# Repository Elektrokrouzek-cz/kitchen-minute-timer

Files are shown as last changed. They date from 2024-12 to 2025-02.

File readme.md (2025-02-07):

# Kitchen minute timer
This is the construction of simple kitchen minute timer based on logical 
circuits (4060, 4040, 4081 and 2x 4017). It was designed for beginners to 
train SMD components soldering (all passive components have 1206 packages).

PCB is 4-layer and was designed using KiCad 8. Fabrication output for JLCPCB is in gerber folder.

Happy soldering!

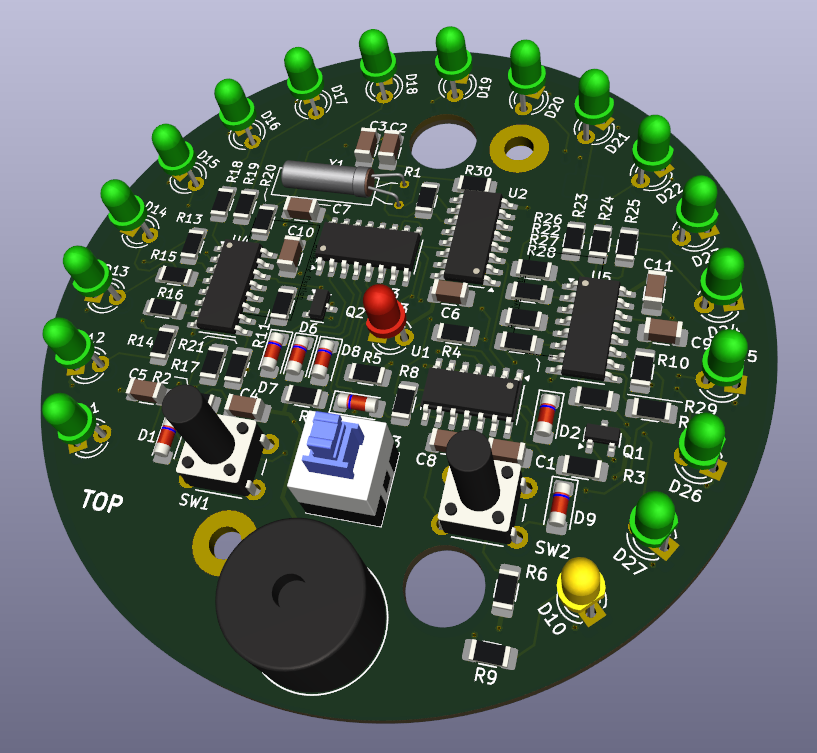
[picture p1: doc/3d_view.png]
3D view

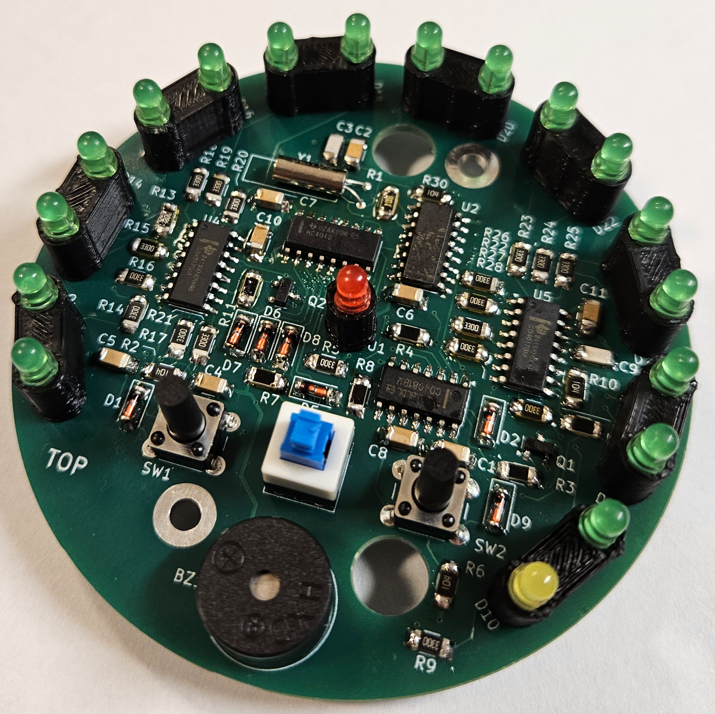
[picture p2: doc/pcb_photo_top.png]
PCB Top

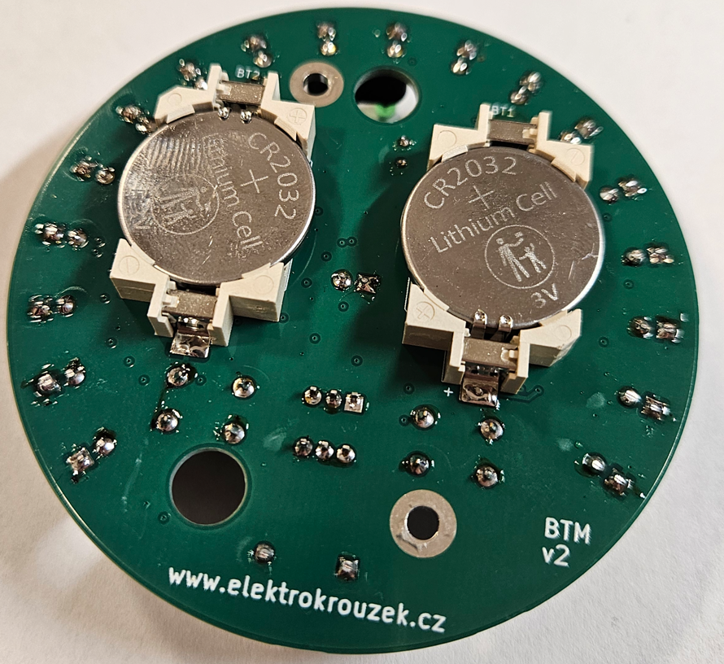
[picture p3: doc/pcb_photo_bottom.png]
PCB Bottom

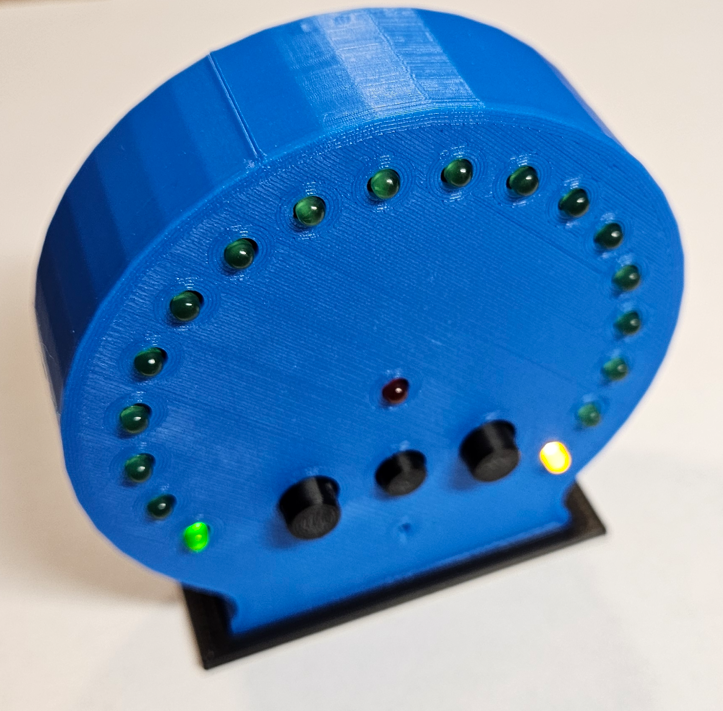
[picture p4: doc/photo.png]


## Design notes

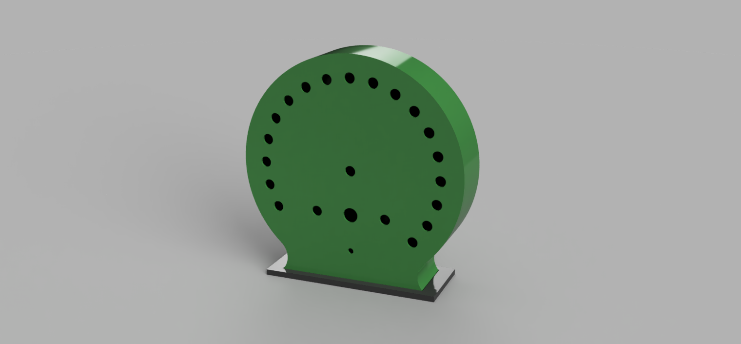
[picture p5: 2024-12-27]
3d/render.png

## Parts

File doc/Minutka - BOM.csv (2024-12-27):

Reference | Value | Footprint | Qty | DNP
BT1,BT2 | DS1092-10-W6L | Battery:BatteryHolder_Renata_SMTU2032-LF_1x2032 | 2
BZ1 | Buzzer | Buzzer_Beeper:MagneticBuzzer_ProSignal_ABI-010-RC | 1
C1,C4,C5,C6,C7,C8,C10,C11 | 100n | Capacitor_SMD:C_1206_3216Metric_Pad1.33x1.80mm_HandSolder | 8
C2 | 100p | Capacitor_SMD:C_1206_3216Metric_Pad1.33x1.80mm_HandSolder | 1
C3 | 22p | Capacitor_SMD:C_1206_3216Metric_Pad1.33x1.80mm_HandSolder | 1
C9 | 47p | Capacitor_SMD:C_1206_3216Metric_Pad1.33x1.80mm_HandSolder | 1
D1,D2,D5,D6,D7,D8,D9 | LL103A | Diode_SMD:D_MiniMELF | 7
D3 | 3mm R | LED_THT:LED_D3.0mm | 1
D10 | 3mm Y | LED_THT:LED_D3.0mm | 1
D11,D12,D13,D14,D15,D16,D17,D18,D19,D20,D21,D22,D23,D24,D25,D26,D27 | 3mm G | LED_THT:LED_D3.0mm | 17
Q1 | BC848 | Package_TO_SOT_SMD:SOT-23 | 1
Q2 | BC858 | Package_TO_SOT_SMD:SOT-23 | 1
R1 | 10M | Resistor_SMD:R_1206_3216Metric_Pad1.30x1.75mm_HandSolder | 1
R2,R6,R10,R30 | 100k | Resistor_SMD:R_1206_3216Metric_Pad1.30x1.75mm_HandSolder | 4
R3,R4,R7,R8,R11,R12 | 10k | Resistor_SMD:R_1206_3216Metric_Pad1.30x1.75mm_HandSolder | 6
R5,R9,R13,R14,R15,R16,R17,R18,R19,R20,R21,R22,R23,R24,R25,R26,R27,R28,R29 | 680R | Resistor_SMD:R_1206_3216Metric_Pad1.30x1.75mm_HandSolder | 19
SW1,SW2 | 6mm | Button_Switch_THT:SW_PUSH_6mm_H13mm | 2
SW3 | PS-22E07L | Button_Switch_THT_Hap:SW_DPDT_7x7_Turbo | 1
U1 | 4081 | Package_SO:SO-14_3.9x8.65mm_P1.27mm | 1
U2 | 4060 | Package_SO:SO-16_3.9x9.9mm_P1.27mm | 1
U3 | 4040 | Package_SO:SO-16_3.9x9.9mm_P1.27mm | 1
U4,U5 | 4017 | Package_SO:SO-16_3.9x9.9mm_P1.27mm | 2
Y1 | 32768Hz | Crystal:Crystal_AT310_D3.0mm_L10.0mm_Horizontal | 1

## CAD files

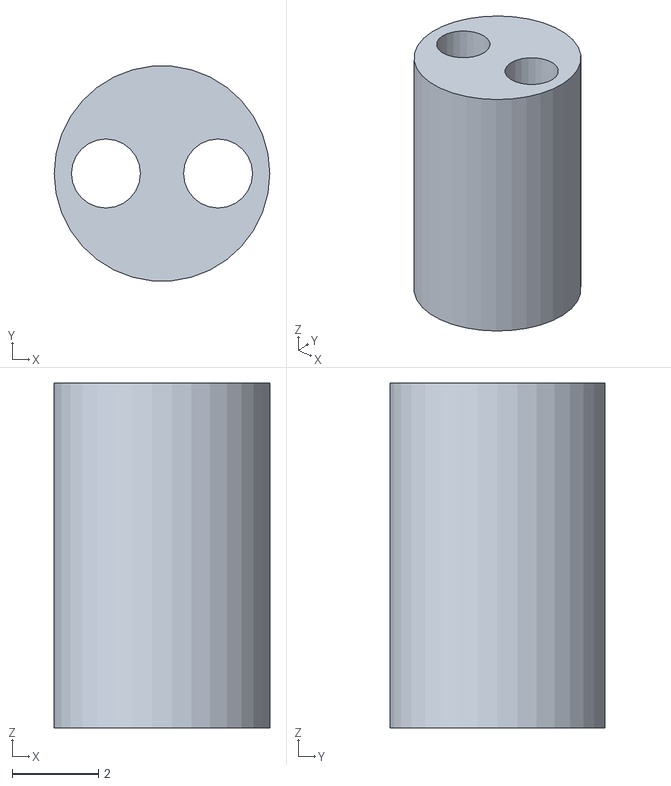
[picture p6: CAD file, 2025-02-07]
3d/spacer-single.stl
5.00 x 4.98 x 8.00

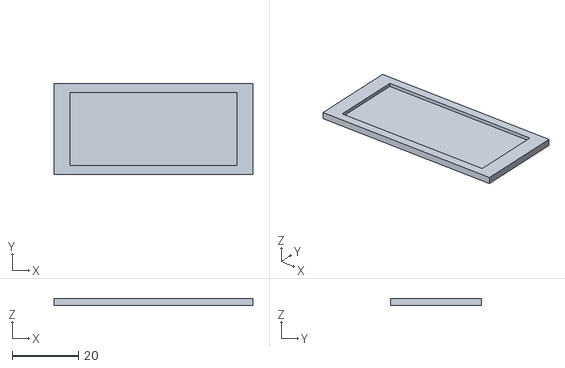
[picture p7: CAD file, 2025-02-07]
3d/stand.stl
60.0 x 27.5 x 2.00

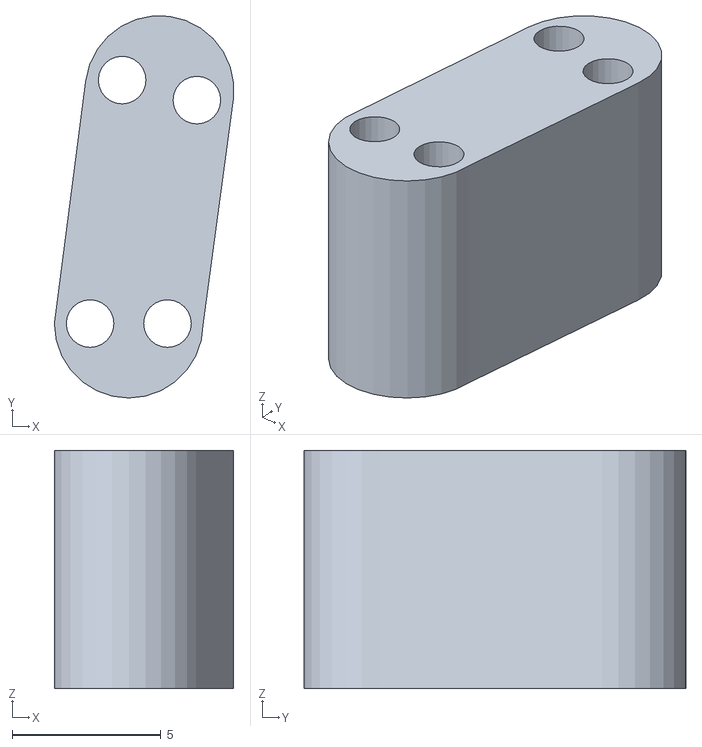
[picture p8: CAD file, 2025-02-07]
3d/spacer-dual.stl
6.02 x 12.8 x 8.00

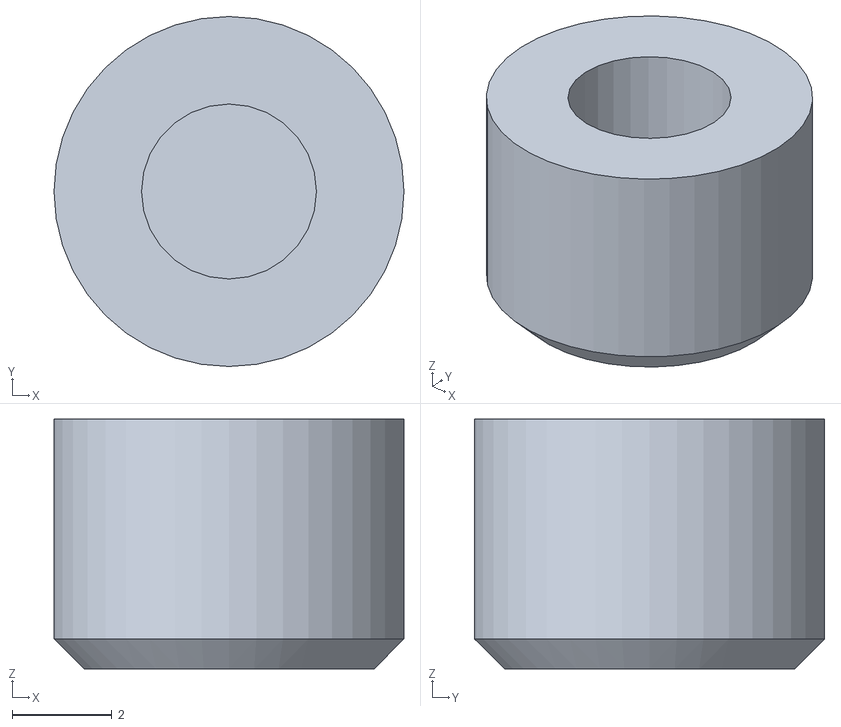
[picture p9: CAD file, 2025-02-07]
3d/button-handle.stl
7.00 x 7.00 x 5.00

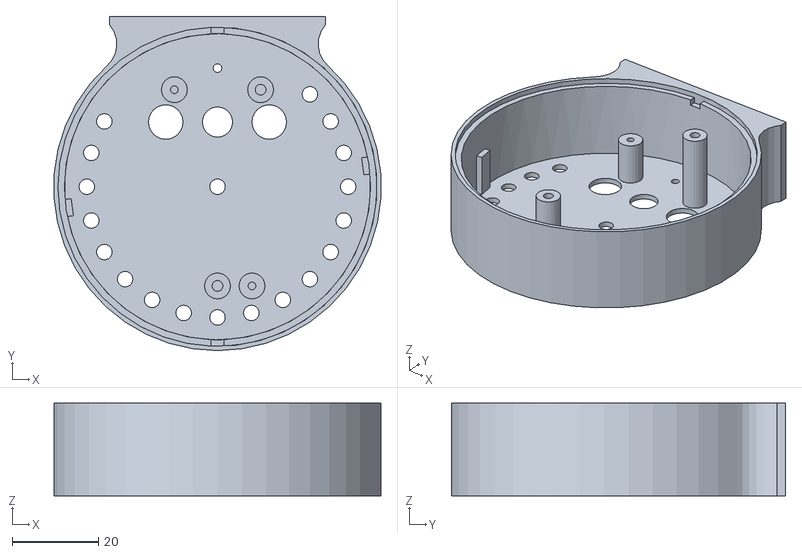
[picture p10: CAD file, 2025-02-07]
3d/body.stl
75.8 x 77.5 x 21.5

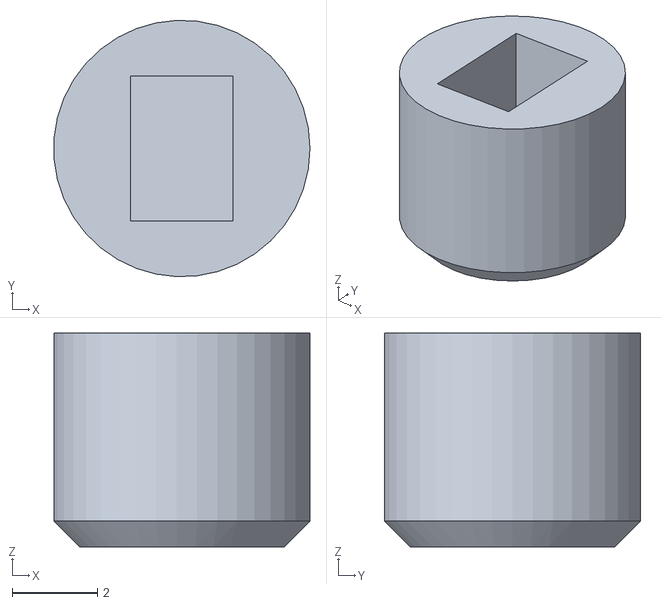
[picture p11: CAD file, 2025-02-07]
3d/switch-handle.stl
5.99 x 6.00 x 5.00

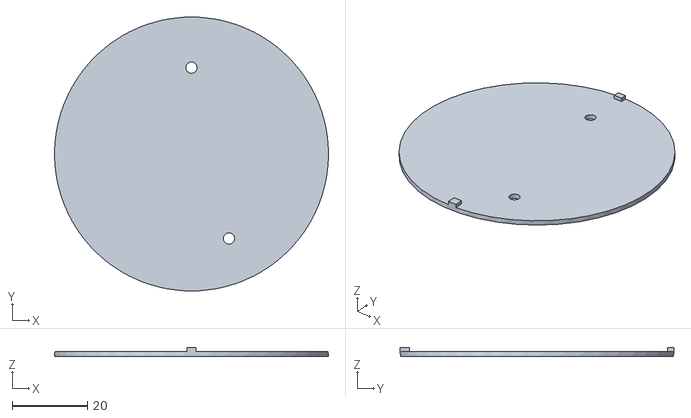
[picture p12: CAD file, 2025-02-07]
3d/cover.stl
73.0 x 73.0 x 2.30

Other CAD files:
3d/Minutka.f3d

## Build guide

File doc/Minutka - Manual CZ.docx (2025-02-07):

# Kuchyňská minutka

## Popis zapojení

Tato konstrukce měří čas v rozmezí 1 až 17 minut. Po uplynutí nastaveného času se rozbliká červená LED a minutka pípá. Celá konstrukce je založena na logických obvodech řady 4000. Časovou základnou je obvod 4060 (U2) s krystalovým oscilátorem 32.768kHz na jehož výstupu je frekvence 2Hz. Ta je využita pro červenou LED a piezo. Základní frekvence 2Hz je vydělena čítačem 4040 (U3) na periodu 1 sekunda pro žlutou LED D10 (indikace provozu) a periodu 1 minuta pomocí 4 vstupového AND obvodu, který je tvořen diodami D5 až D8 a rezistorem R7.

Perioda 1 minuta je použita jako vstup do Johnsnova čítače 4017 (U4). Za ním je zapojen další čítač stejného typu. Tato kombinace umožňuje čítání až do 17 minut.

Minutka se nastavuje pomocí tlačítka SW2. To generuje pulzy pro první čítač U4 a zároveň resetuje minutovou děličku U3. Tlačítko SW1 resetuje celou minutku na výchozí čas 17 minut.

Po uplynutí nastaveného času se rozbliká LED D3 a začne pípat piezo BZ1. Čítání dále neprobíhá, dokud není stisknuto tlačítko SW1 (reset) – obvod U5 má blokovaný vstup CKEN.

## Popis sestavení

Nejprve osadíme integrované obvody U1 až U5. Je to z toho důvodu, že k jejich vývodům bychom se pájecí stanicí špatně dostávali, kdybychom nejprve osadili pasivní součástky. Pokračujeme osazením rezistorů a kondenzátorů. Poté osadíme diody D1, D2, D5 až D9 a krystal Y1. Pokračujeme osazením tlačítek SW1, SW2, vypínače SW3 a pieza BZ1. Pozor – u vypínače SW3 je nutné dodržet správnou orientaci (viz obrázek).

Na závěr osadíme LED diody, které vložíme do připravených plastových podložek. Vždy pájíme nejprve jeden vývod, LED diodu srovnáme a poté zapájíme druhý vývod.

Ze spodní strany osadíme držáky baterií. Pozor na polaritu!

## Oživení

Pokud jste pracovali pečlivě mělo by zapojení fungovat na první pokus. Po zapnutí by měla blikat žlutá LED. Mačkáním tlačítka SW2 by se měly posouvat zelené LED až k 1 minutě a následně rozblikat červená a piezo by mělo pípat.

## Seznam součástek

Označení | Hodnota | Počet
BT1,BT2 | DS1092-10-W6L | 2
BZ1 | Buzzer | 1
C1,C4,C5,C6,C7,C8,C10,C11 | 100n | 8
C2 | 100p | 1
C3 | 22p | 1
C9 | 47p | 1
D1,D2,D5,D6,D7,D8,D9 | LL103A | 7
D3 | 3mm R | 1
D10 | 3mm Y | 1
D11,D12,D13,D14,D15,D16,D17,D18,D19,D20,D21,D22,D23,D24,D25,D26,D27 | 3mm G | 17
Q1 | BC848 | 1
Q2 | BC858 | 1
R1 | 10M | 1
R2,R6,R10,R30 | 100k | 4
R3,R4,R7,R8,R11,R12 | 10k | 6
R5,R9,R13,R14,R15,R16,R17,R18,R19,R20,R21,R22,R23,R24,R25,R26,R27,R28,R29 | 680R | 19
SW1,SW2 | 6mm | 2
SW3 | PS-22E07L | 1
U1 | 4081 | 1
U2 | 4060 | 1
U3 | 4040 | 1
U4,U5 | 4017 | 2
Y1 | 32768Hz | 1

## Orientace tlačítka

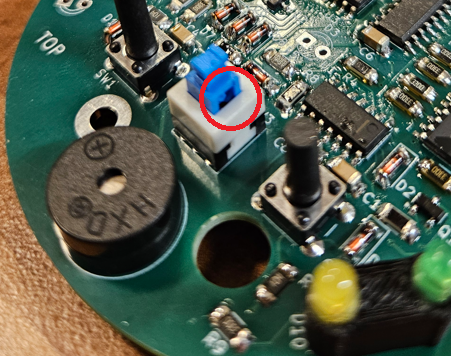
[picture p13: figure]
Obsah obrázku elektronika, Elektronické inženýrství, obvod, Elektronická součástka Popis byl vytvořen automaticky

## Osazovací výkres

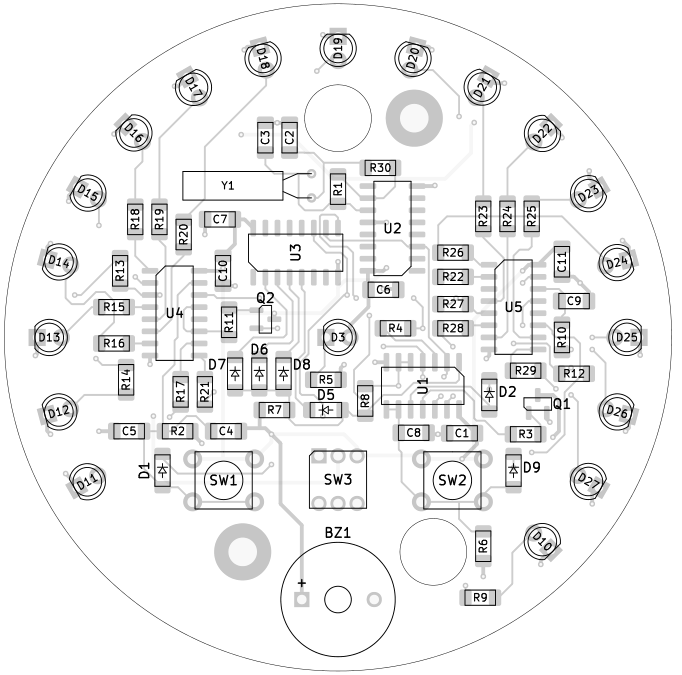
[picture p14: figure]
Obsah obrázku kruh, text, diagram, kresba Popis byl vytvořen automaticky

## Schéma zapojení

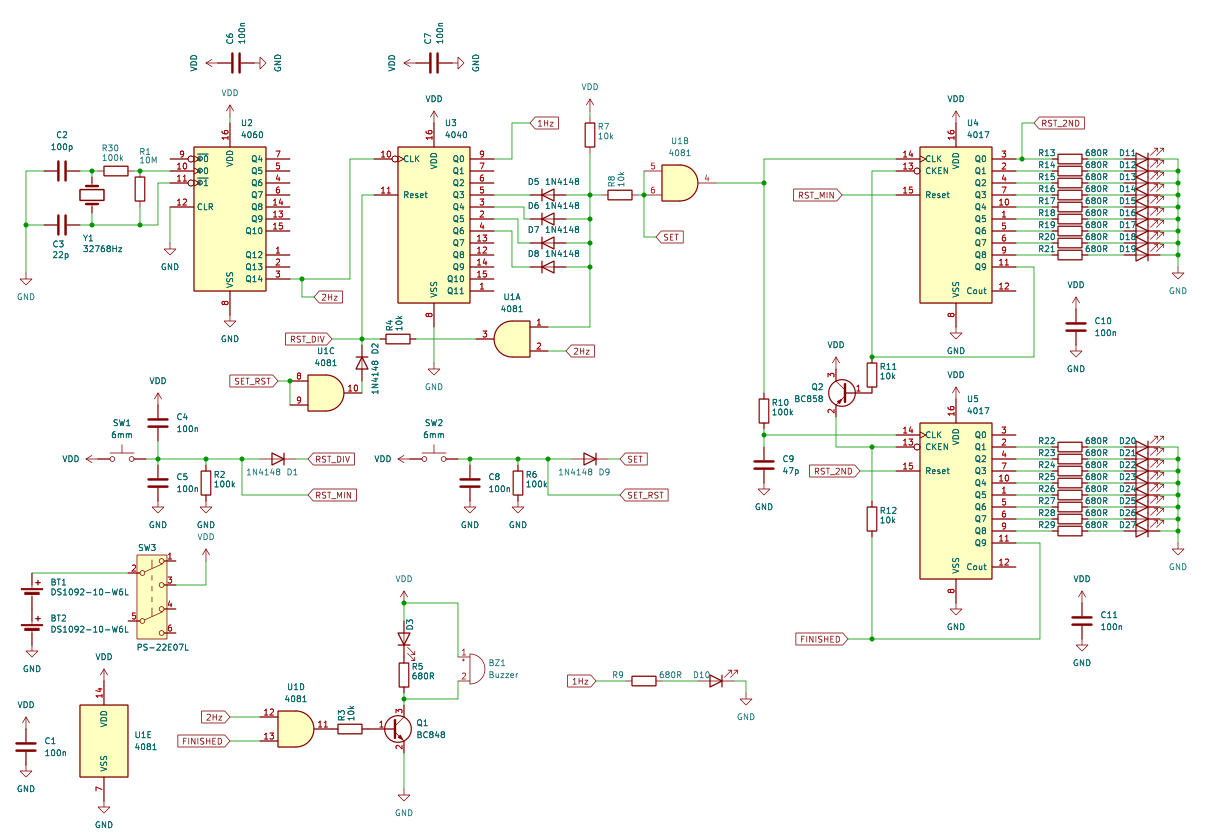
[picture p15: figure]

www.elektrokrouzek.cz

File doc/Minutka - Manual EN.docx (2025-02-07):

# Kitchen minute timer

## Schematic description

This construction measures the time in range 1 to 17 minutes. It blinks red LED and beeps after the time is up. The construction is based on 4000 family logical circuits. Time base is created by 4060 circuit with crystal oscillator. It generates 2Hz frequency at its output. This frequency is used for red LED and piezo buzzer. 2Hz frequency is divided by 4040 counter (U3) to 1 second period for yellow LED D10 (operation indication) and 1 minute period using 4 input AND circuit based on D5 to D8 diodes and resistor R7.

1 minute period is used as and input for Johnson counter 4017 (U4). There is another counter of the same type connected in cascade. This combination allows counting up to 17 minutes.

Minute timer is set using button SW2. It generates pulses for first counter U4 and it also resets minute divider U3. Button SW1 is used for reset the whole circuit back to 17 minutes.

LED D3 blinks and piezo buzzer beeps after the time is up. Counters stops counting until SW1 button is pressed (reset) – U5 CKEN input is blocked.

## Construction

U1 to U5 shall be populated first. The reason for that is to have a good access to IC terminals that can be blocked by passive components. Then continue by populating all passive components (resistors and capacitors). Diodes D1, D2, D5 to D9 and crystal Y1 shall be populated next. Then buttons SW1, SW2 and switch SW3 are soldered. Caution – take care of SW3 orientation (see photo).

LEDs are populated at the end. Please them to plastic spacers. Always solder one LED terminal, align it and then solder second terminal.

Battery holders are soldered at the bottom side. Take care of the polarity!

## How to get it into service

It should work on the first try when everything was soldered well. Yellow LED should blink after power up. Green LEDs should shift up to 1 minute by pressing SW2 button. Then red LED should blink and piezo buzzer should beep.

## Bill of material

Annotation | Type | Qty
BT1,BT2 | DS1092-10-W6L | 2
BZ1 | Buzzer | 1
C1,C4,C5,C6,C7,C8,C10,C11 | 100n | 8
C2 | 100p | 1
C3 | 22p | 1
C9 | 47p | 1
D1,D2,D5,D6,D7,D8,D9 | LL103A | 7
D3 | 3mm R | 1
D10 | 3mm Y | 1
D11,D12,D13,D14,D15,D16,D17,D18,D19,D20,D21,D22,D23,D24,D25,D26,D27 | 3mm G | 17
Q1 | BC848 | 1
Q2 | BC858 | 1
R1 | 10M | 1
R2,R6,R10,R30 | 100k | 4
R3,R4,R7,R8,R11,R12 | 10k | 6
R5,R9,R13,R14,R15,R16,R17,R18,R19,R20,R21,R22,R23,R24,R25,R26,R27,R28,R29 | 680R | 19
SW1,SW2 | 6mm | 2
SW3 | PS-22E07L | 1
U1 | 4081 | 1
U2 | 4060 | 1
U3 | 4040 | 1
U4,U5 | 4017 | 2
Y1 | 32768Hz | 1

## Button orientation


## Assembly

Obsah obrázku kruh, text, diagram, kresba Popis byl vytvořen automaticky

## Schematic


www.elektrokrouzek.cz

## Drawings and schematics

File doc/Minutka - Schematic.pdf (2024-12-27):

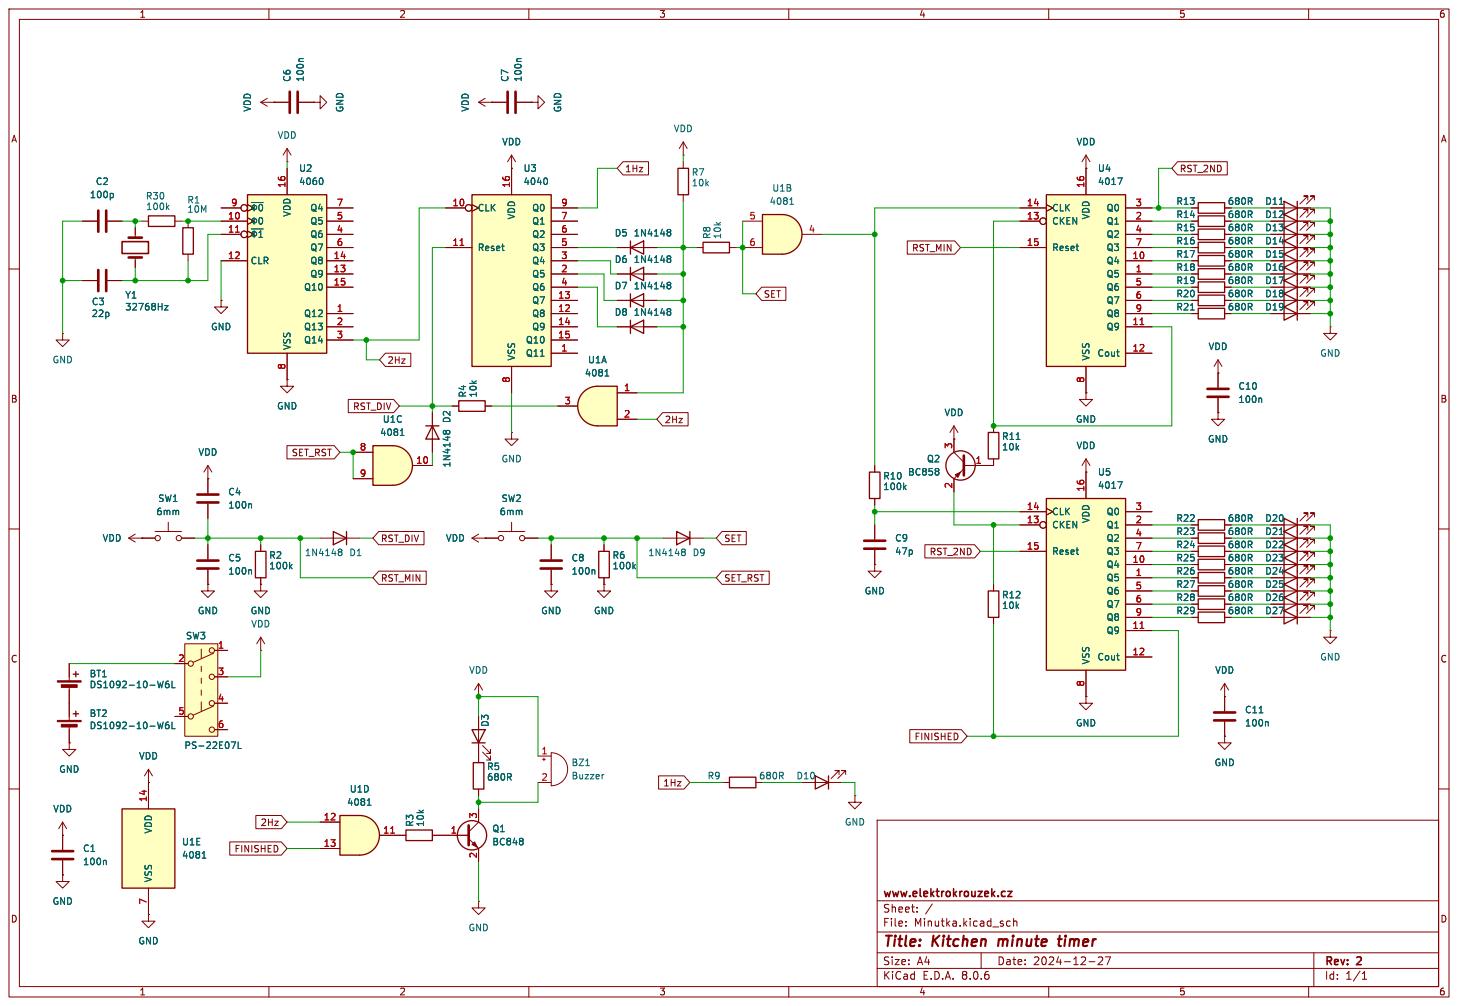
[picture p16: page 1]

Id: 1/1 Title: Kitchen minute timer File: Minutka.kicad_sch Sheet: / www.elektrokrouzek.cz GND

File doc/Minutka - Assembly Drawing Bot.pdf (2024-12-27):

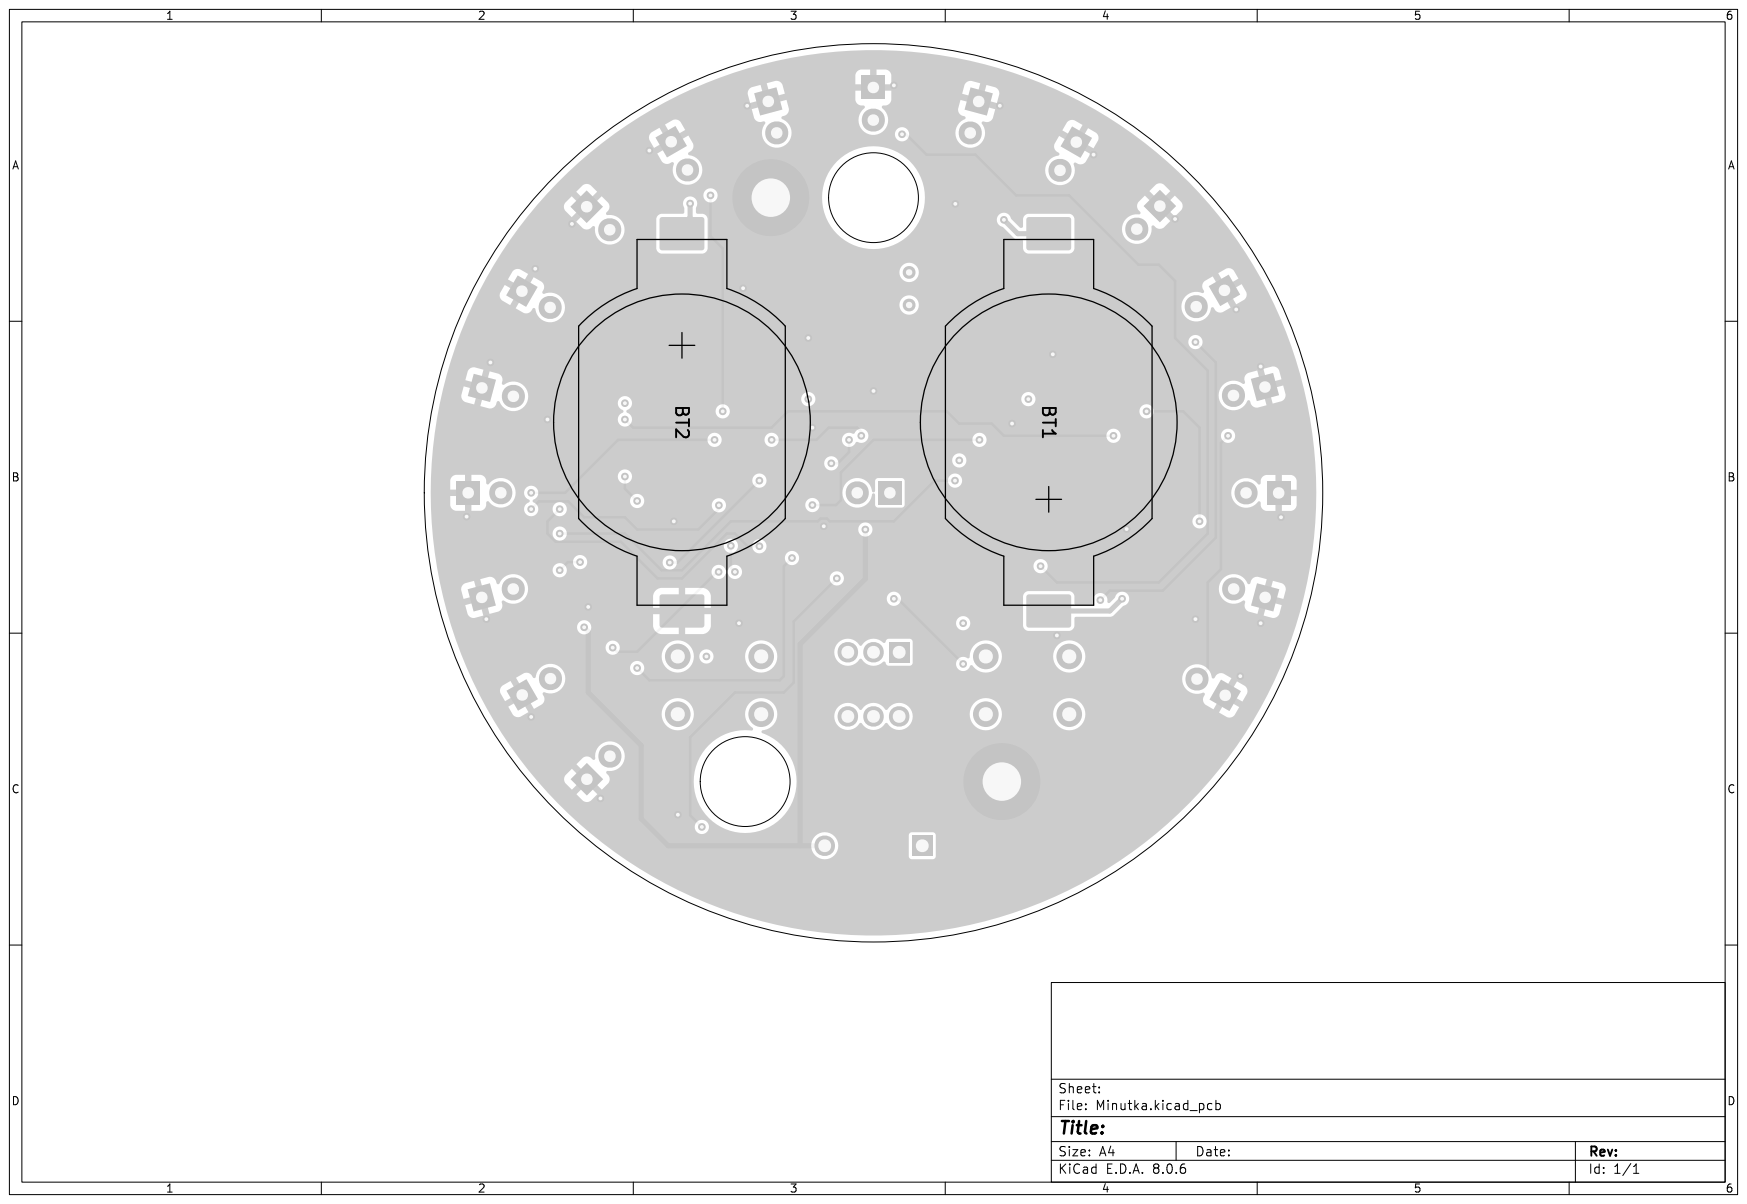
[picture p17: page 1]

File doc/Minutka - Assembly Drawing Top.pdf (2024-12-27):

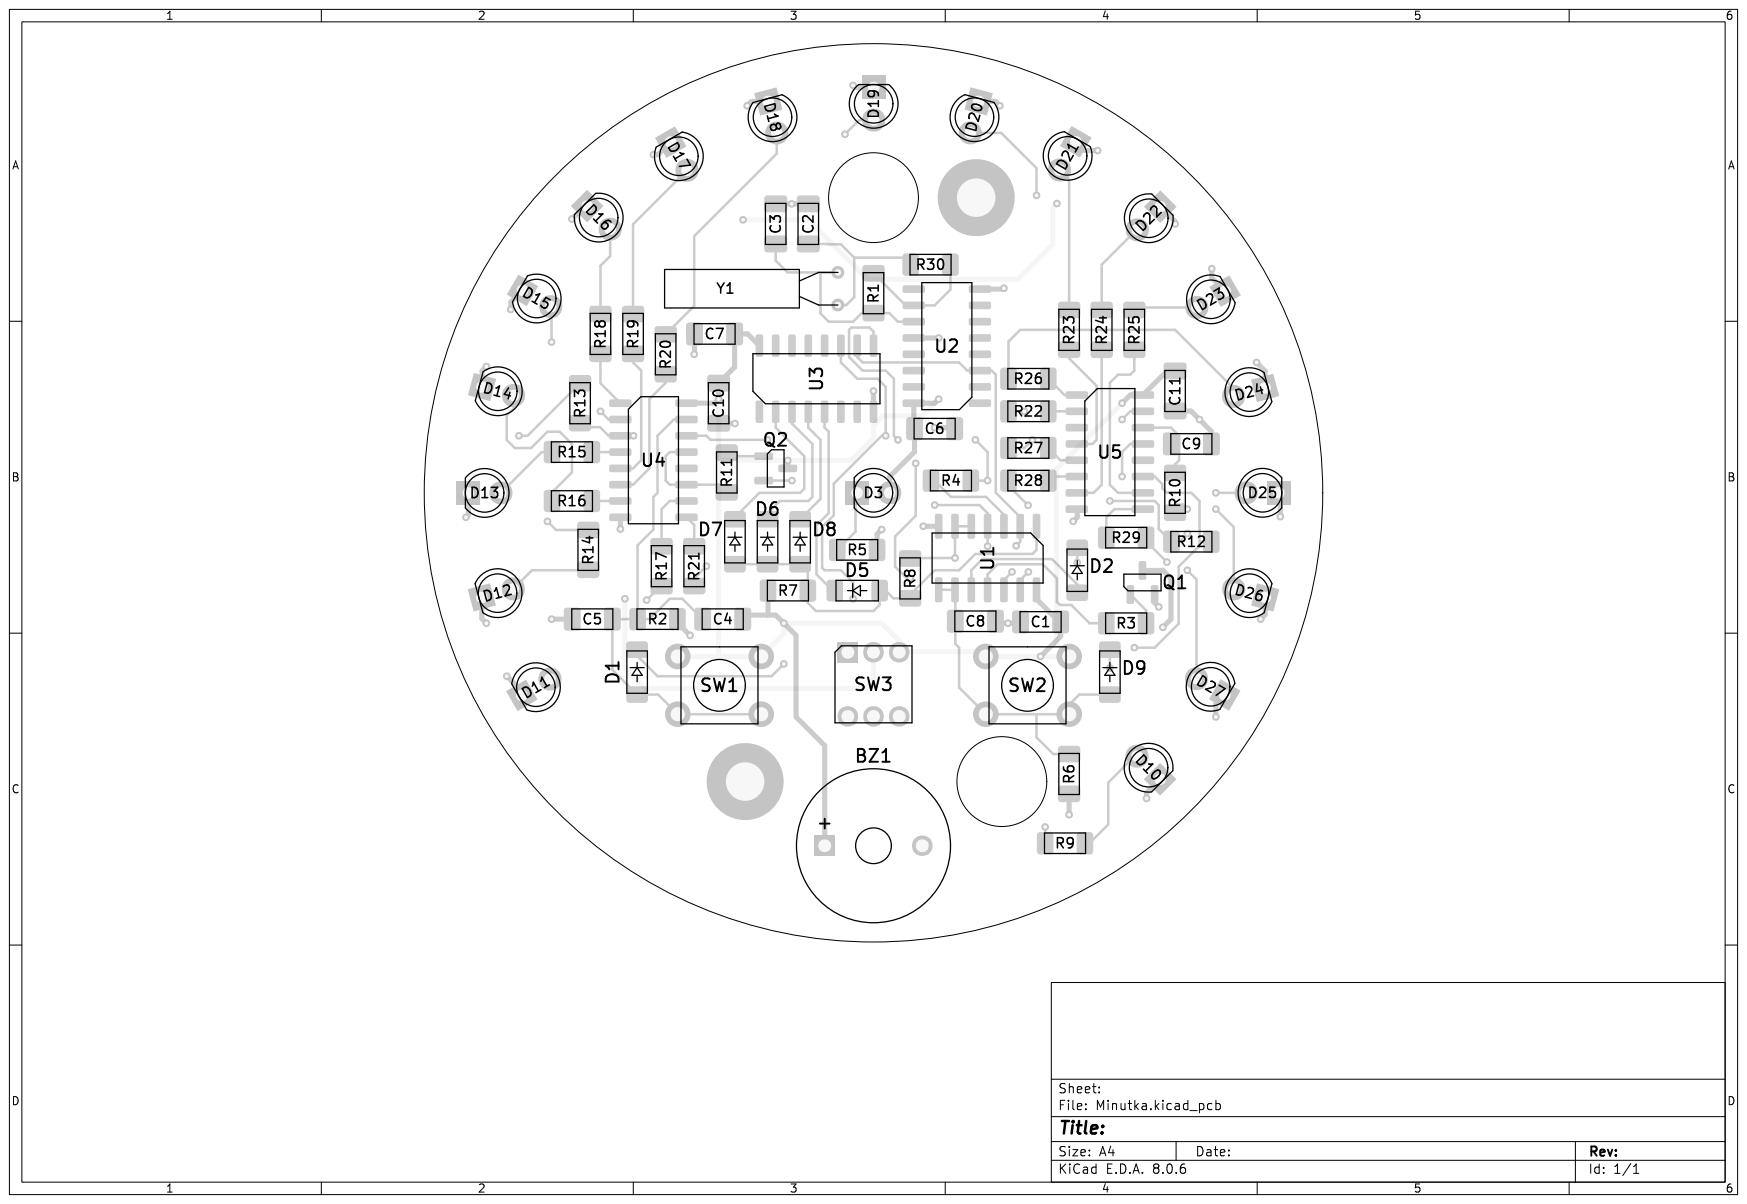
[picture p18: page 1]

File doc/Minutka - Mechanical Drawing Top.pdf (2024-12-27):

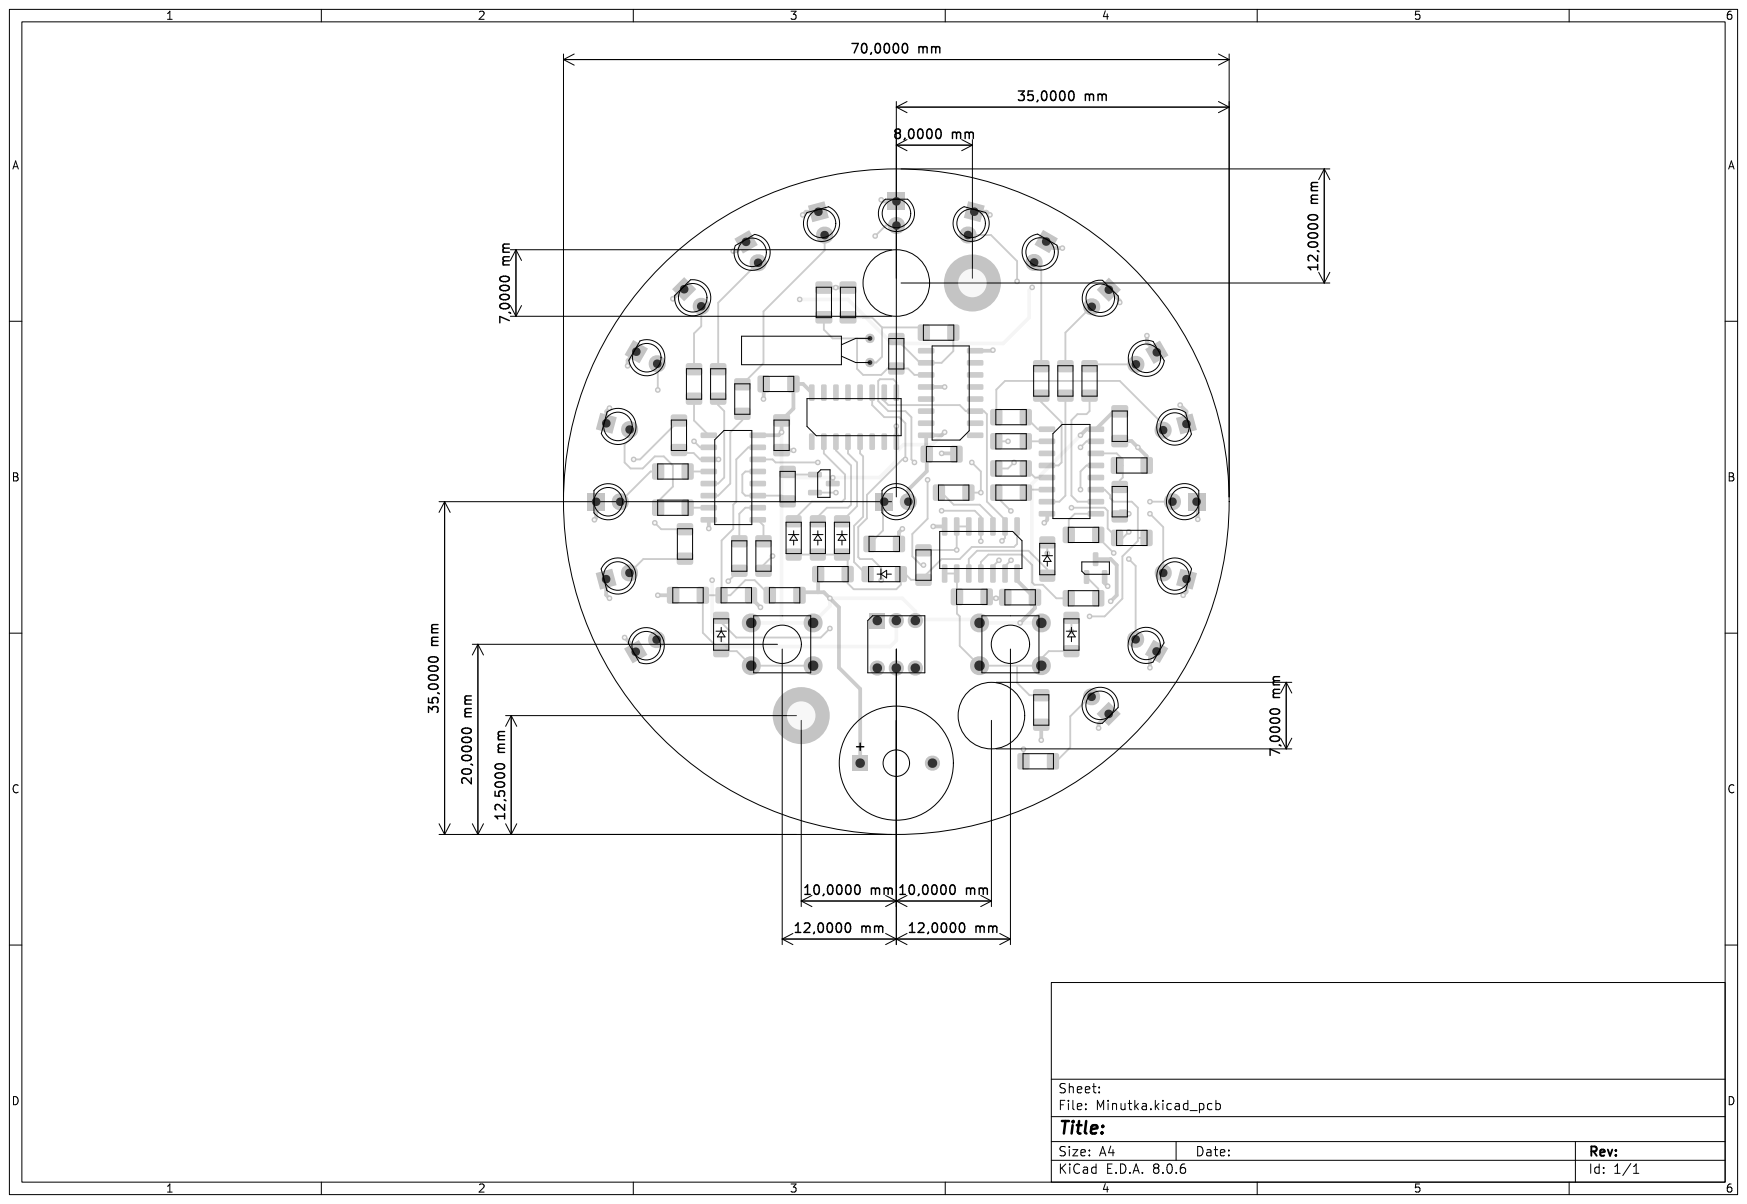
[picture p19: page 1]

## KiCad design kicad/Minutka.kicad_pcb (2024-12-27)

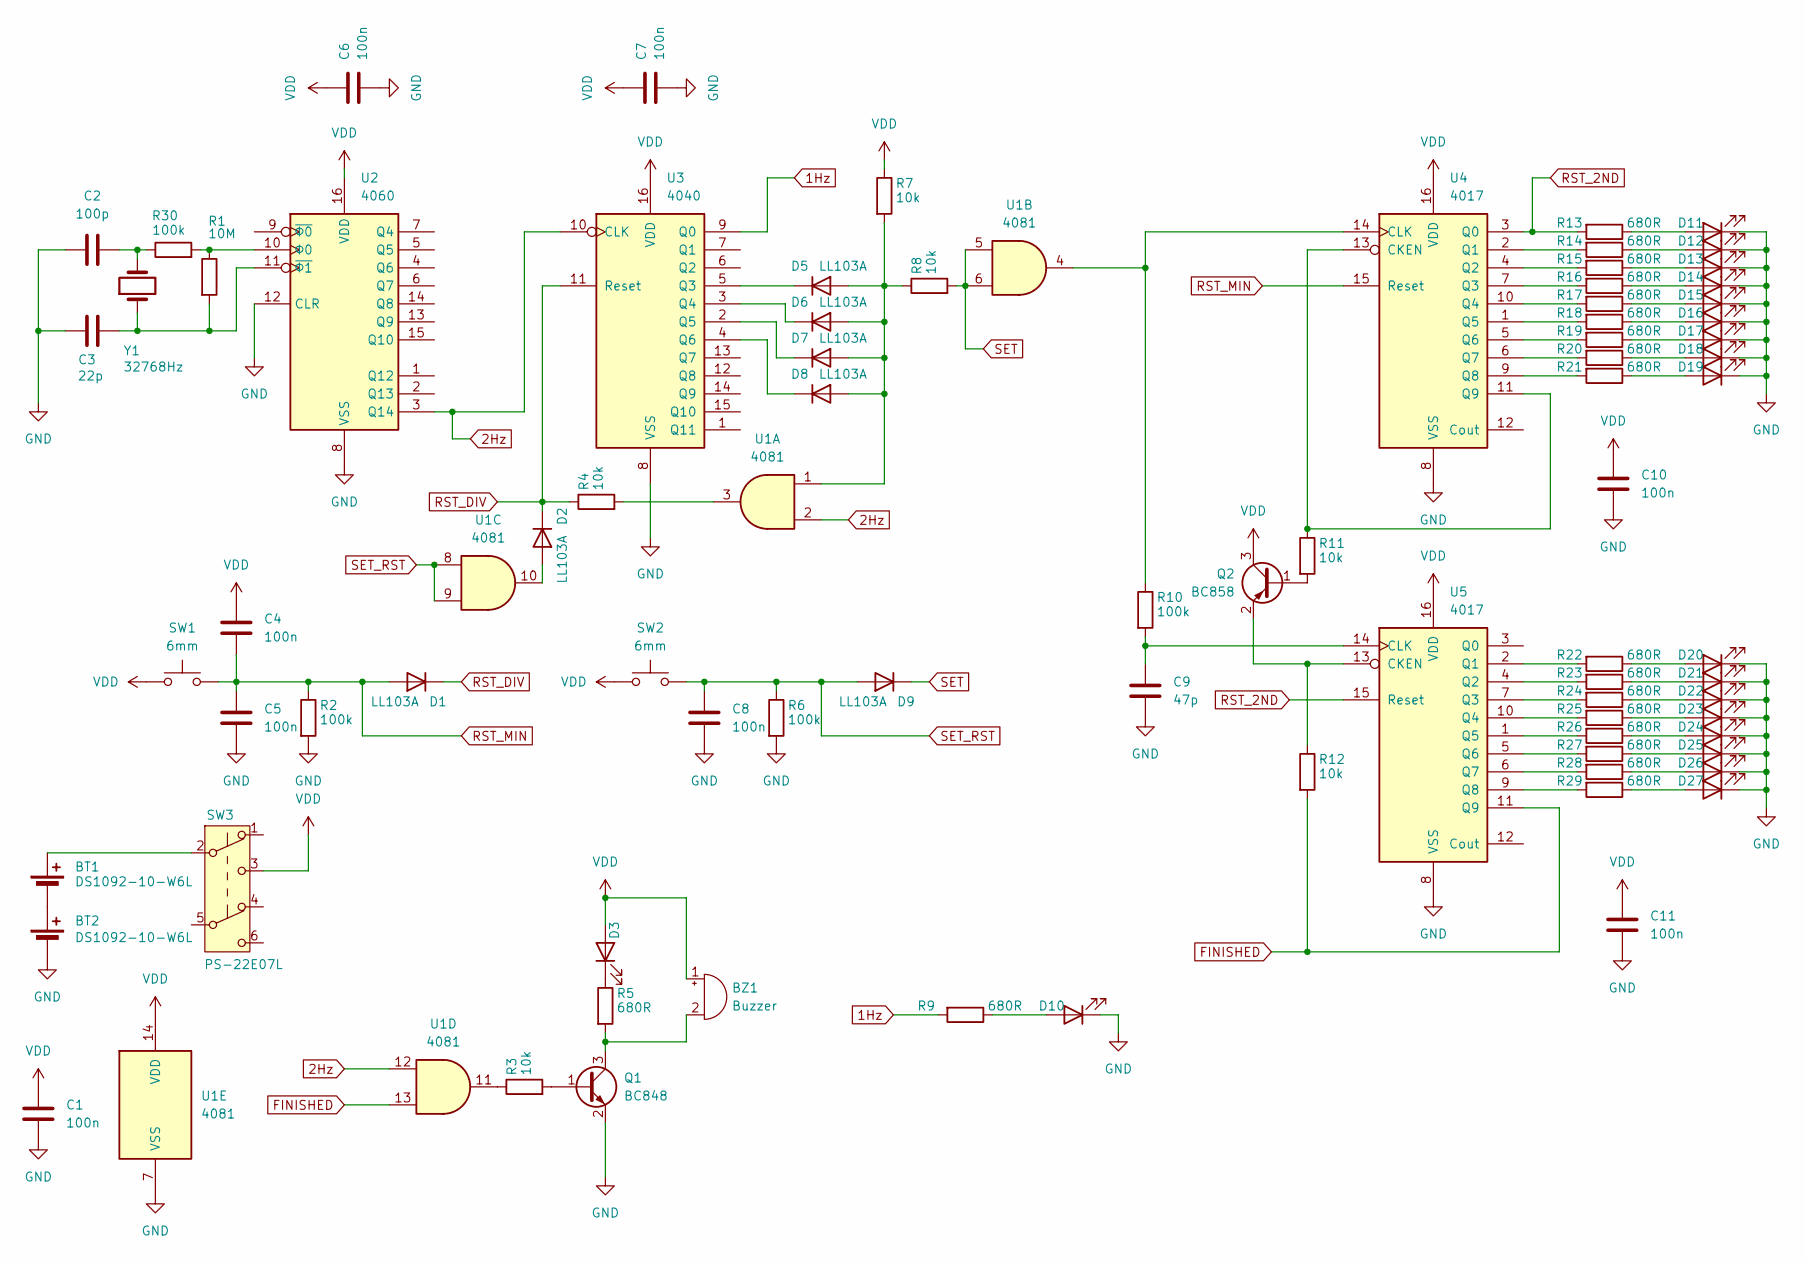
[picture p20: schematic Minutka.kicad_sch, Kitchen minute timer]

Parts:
BT1, BT2: DS1092-10-W6L; BatteryHolder_Renata_SMTU2032-LF_1x2032
BZ1: Buzzer; MagneticBuzzer_ProSignal_ABI-010-RC
C1, C4, C5, C6, C7, C8, C10, C11: 100n; C_1206_3216Metric_Pad1.33x1.80mm_HandSolder
C2: 100p; C_1206_3216Metric_Pad1.33x1.80mm_HandSolder
C3: 22p; C_1206_3216Metric_Pad1.33x1.80mm_HandSolder
C9: 47p; C_1206_3216Metric_Pad1.33x1.80mm_HandSolder
D1, D2, D5, D6, D7, D8, D9: LL103A; D_MiniMELF
D3: 3mm R; LED_D3.0mm
D10: 3mm Y; LED_D3.0mm
D11, D12, D13, D14, D15, D16, D17, D18, D19, D20, D21, D22, D23, D24, D25, D26, D27: 3mm G; LED_D3.0mm
Q1: BC848; SOT-23
Q2: BC858; SOT-23
R1: 10M; R_1206_3216Metric_Pad1.30x1.75mm_HandSolder
R2, R6, R10, R30: 100k; R_1206_3216Metric_Pad1.30x1.75mm_HandSolder
R3, R4, R7, R8, R11, R12: 10k; R_1206_3216Metric_Pad1.30x1.75mm_HandSolder
R5, R9, R13, R14, R15, R16, R17, R18, R19, R20, R21, R22, R23, R24, R25, R26, R27, R28, R29: 680R; R_1206_3216Metric_Pad1.30x1.75mm_HandSolder
SW1, SW2: 6mm; SW_PUSH_6mm_H13mm
SW3: PS-22E07L; SW_DPDT_7x7_Turbo
U1: 4081; SO-14_3.9x8.65mm_P1.27mm
U2: 4060; SO-16_3.9x9.9mm_P1.27mm
U3: 4040; SO-16_3.9x9.9mm_P1.27mm
U4, U5: 4017; SO-16_3.9x9.9mm_P1.27mm
Y1: 32768Hz; Crystal_AT310_D3.0mm_L10.0mm_Horizontal

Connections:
1Hz: R9.2, U3.9 (Q0)
2Hz: U1.2, U1.12, U2.3 (Q14), U3.10 (CLK)
FINISHED: R12.2, U1.13, U5.11 (Q9)
GND: BT2.2 (-), C1.1, C2.1, C3.1, C5.1, C6.1, C7.1, C8.1, C9.1, C10.1, C11.1, D10.1 (K), D11.1 (K), D12.1 (K), D13.1 (K), D14.1 (K), D15.1 (K), D16.1 (K), D17.1 (K), D18.1 (K), D19.1 (K), D20.1 (K), D21.1 (K), D22.1 (K), D23.1 (K), D24.1 (K), D25.1 (K), D26.1 (K), D27.1 (K), Q1.2 (E), R2.2, R6.2, U1.7 (VSS), U2.8 (VSS), U2.12 (CLR), U3.8 (VSS), U4.8 (VSS), U5.8 (VSS)
unnamed: BT1.1 (+), SW3.2 (B)
unnamed: BT1.2 (-), BT2.1 (+)
unnamed: BZ1.2 (-), Q1.3 (C), R5.2
unnamed: C2.2, R30.1, Y1.2
unnamed: D2.2 (A), U1.10
unnamed: D3.1 (K), R5.1
unnamed: D5.2 (A), D6.2 (A), D7.2 (A), D8.2 (A), R7.2, R8.1, U1.1
unnamed: D5.1 (K), U3.5 (Q3)
unnamed: D6.1 (K), U3.3 (Q4)
unnamed: D7.1 (K), U3.2 (Q5)
unnamed: D8.1 (K), U3.4 (Q6)
unnamed: D10.2 (A), R9.1
unnamed: D11.2 (A), R13.1
unnamed: D12.2 (A), R14.1
unnamed: D13.2 (A), R15.1
unnamed: D14.2 (A), R16.1
unnamed: D15.2 (A), R17.1
unnamed: D16.2 (A), R18.1
unnamed: D17.2 (A), R19.1
unnamed: D18.2 (A), R20.1
unnamed: D19.2 (A), R21.1
unnamed: D20.2 (A), R22.1
unnamed: D21.2 (A), R23.1
unnamed: D22.2 (A), R24.1
unnamed: D23.2 (A), R25.1
unnamed: D24.2 (A), R26.1
unnamed: D25.2 (A), R27.1
unnamed: D26.2 (A), R28.1
unnamed: D27.2 (A), R29.1
unnamed: Q1.1 (B), R3.2
unnamed: Q2.1 (B), R11.2
unnamed: Q2.2 (E), R12.1, U5.13 (CKEN)
unnamed: R3.1, U1.11
unnamed: R4.2, U1.3
unnamed: C3.2, R1.2, U2.11 (~Φ1), Y1.1
unnamed: R1.1, R30.2, U2.10 (Φ0)
unnamed: R11.1, U4.11 (Q9), U4.13 (CKEN)
unnamed: R10.1, U1.4, U4.14 (CLK)
unnamed: R14.2, U4.2 (Q1)
unnamed: R15.2, U4.4 (Q2)
unnamed: R16.2, U4.7 (Q3)
unnamed: R17.2, U4.10 (Q4)
unnamed: R18.2, U4.1 (Q5)
unnamed: R19.2, U4.5 (Q6)
unnamed: R20.2, U4.6 (Q7)
unnamed: R21.2, U4.9 (Q8)
unnamed: C9.2, R10.2, U5.14 (CLK)
unnamed: R22.2, U5.2 (Q1)
unnamed: R23.2, U5.4 (Q2)
unnamed: R24.2, U5.7 (Q3)
unnamed: R25.2, U5.10 (Q4)
unnamed: R26.2, U5.1 (Q5)
unnamed: R27.2, U5.5 (Q6)
unnamed: R28.2, U5.6 (Q7)
unnamed: R29.2, U5.9 (Q8)
RST_2ND: R13.2, U4.3 (Q0), U5.15 (Reset)
RST_DIV: D1.1 (K), D2.1 (K), R4.1, U3.11 (Reset)
RST_MIN: C4.1, C5.2, D1.2 (A), R2.1, SW1.2, U4.15 (Reset)
SET: D9.1 (K), R8.2, U1.5, U1.6
SET_RST: C8.2, D9.2 (A), R6.1, SW2.2, U1.8, U1.9
VDD: BZ1.1 (+), C1.2, C4.2, C6.2, C7.2, C10.2, C11.2, D3.2 (A), Q2.3 (C), R7.1, SW1.1, SW2.1, SW3.3 (C), U1.14 (VDD), U2.16 (VDD), U3.16 (VDD), U4.16 (VDD), U5.16 (VDD)

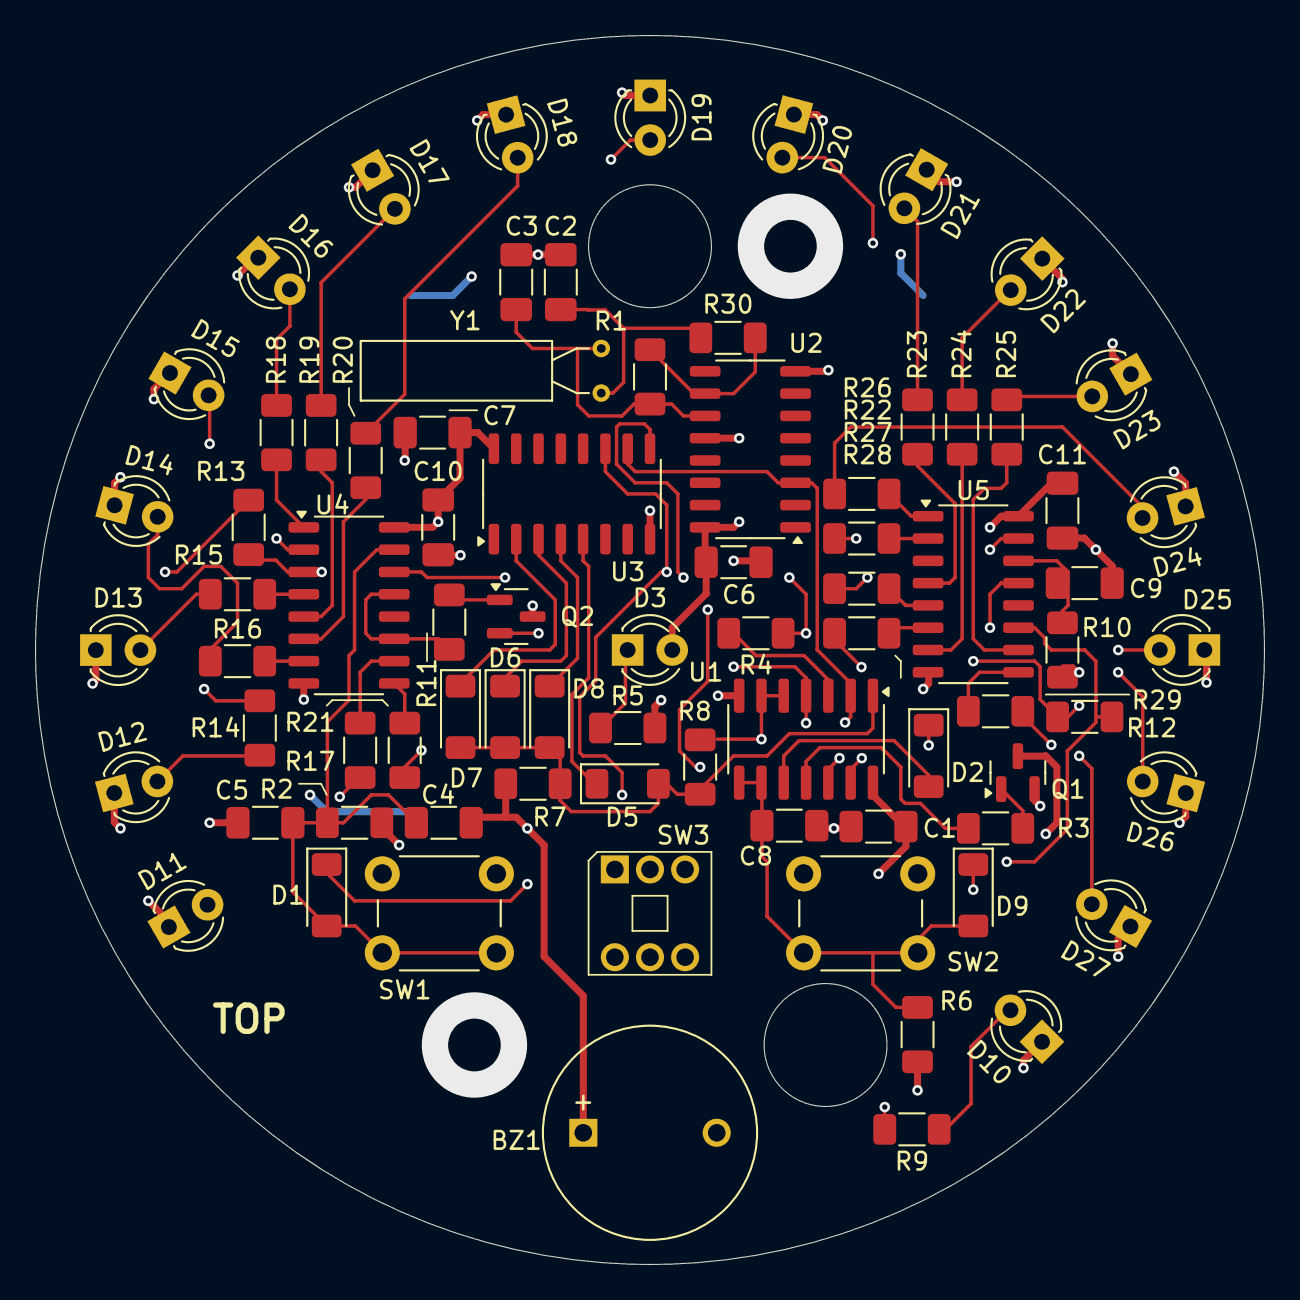
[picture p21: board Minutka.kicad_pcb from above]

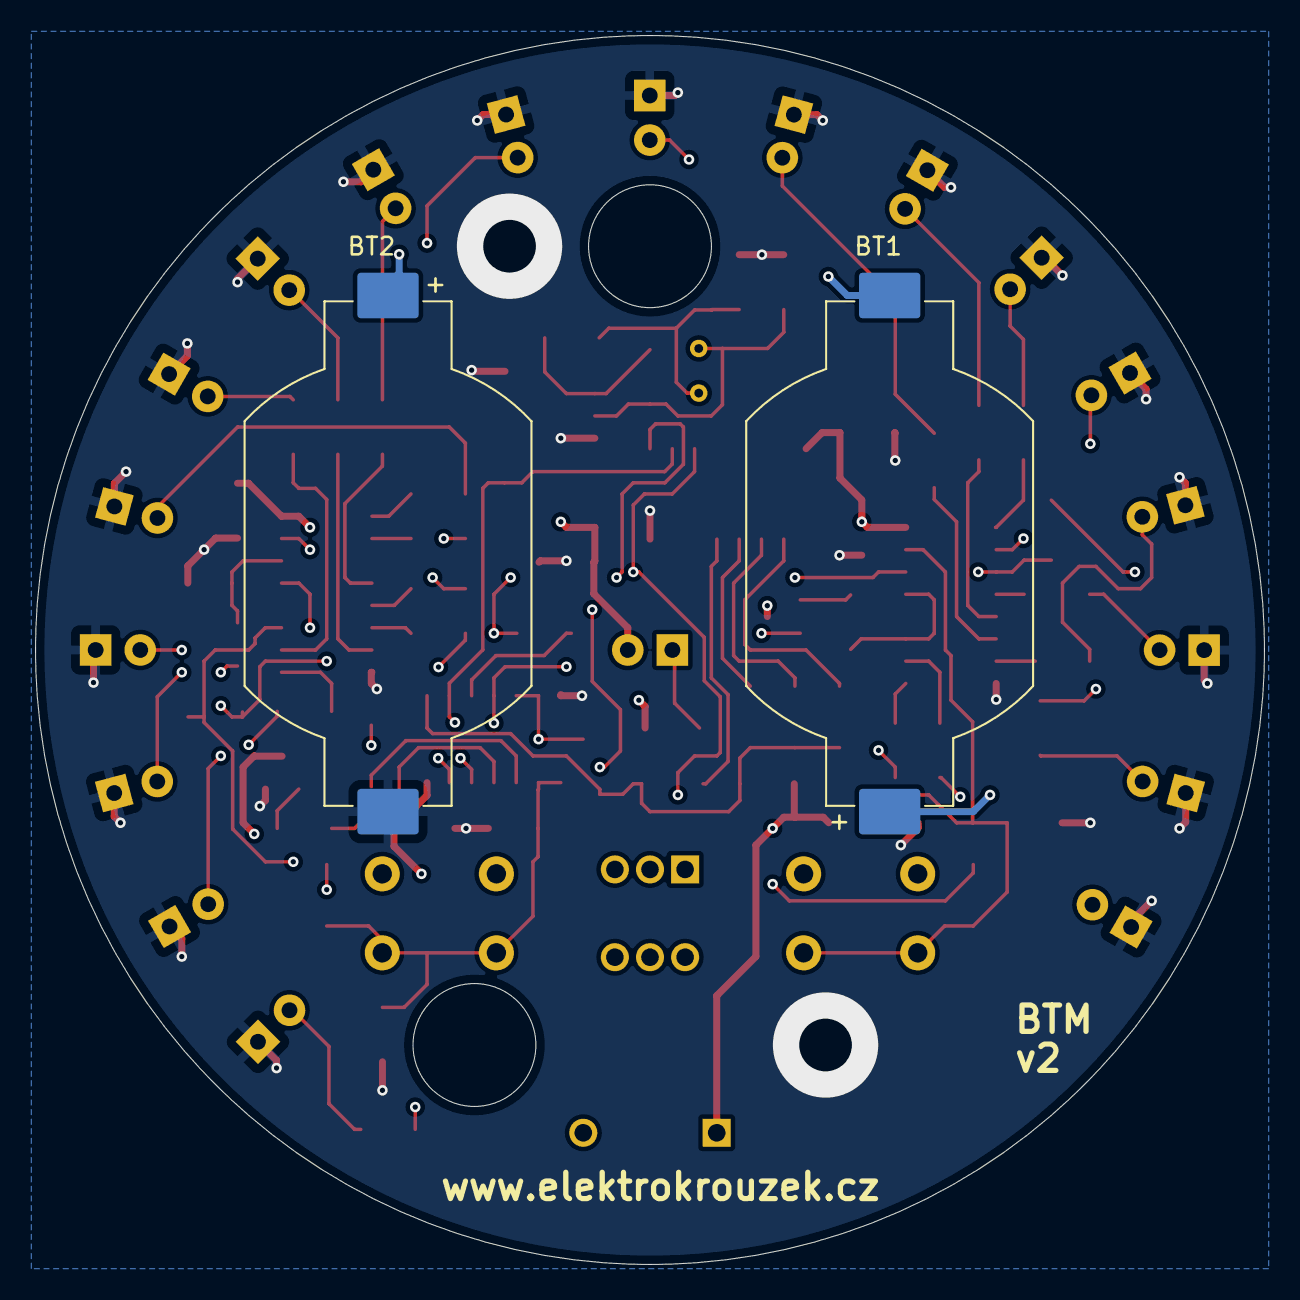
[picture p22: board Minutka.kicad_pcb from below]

Board: 4 copper layers, 70.0 x 70.0 mm, 81 parts (2 on the bottom side), 65 nets.

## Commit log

2024-12-27 LED 3D model changes (color)
    [Minutka.kicad_pcb]
2024-12-27 Preliminary 3D model
    [Minutka.f3d, body.stl, cover.stl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]
2025-02-07 Final 3D models, manuals added
    [Minutka.f3d, body.stl, button-handle.stl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]
